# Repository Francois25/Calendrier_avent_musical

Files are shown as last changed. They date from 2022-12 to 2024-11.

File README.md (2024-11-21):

# Calendrier de l'Avent musical :

Ce calendrier de l'Avent utlise un ESp32-TTGO-T-Display permettant d'alimenter un circuit sur lequel 2 circuits intégrés CD4511 sont couplés à un circuit intégré CD40106 pour allumé aléatoirement 24 leds et jouer des musiques de Noël.
Les leds sont placé sur un plateau en bois décoré de 23 maisonnettes et une église simulants les 24 jours avant le jour de Noël).
Le déclenchement des musiques et de l'éclairage par clignottement aléatoire est défini selon la date et l'heure, tous les jours à 18h30 l'éclairage s'allume et il s'éteind automatiquement à 22h, il est toutefois possible d'allumer ou d'éteindre manuellement ces fonctions à l'aide de bouton sensitif.
Lors de l'appui sur un jour souhaité sur la partie NOEL de la décoration, la led relié s'illumine avec plus d'intensité pour repérer facilement la maisonnette correspondante.

# Firmware Micropython :
Le firmware utilisé est Micropython, disponible dans le répertoire [Firmware](https://github.com/Francois25/Calendrier_avent_musical/tree/main/firmware)

# Fonctionnement :
Dans un premier temps il faut créer un fichier config.py qui contiendra les valeur pour la connection réseau, ssid = "your_ssid" et password = "your_password".
Lors de la mise sous tension du module celui-ci va se connecter à votre réseau wifi interne et récupérer les données NTP (Network Time Protocol), la date et l'heure pour faire simple.

Au début du fichier "main" il y a les parametre des heures qu'on souhaite pour l'automatisation de l'alumage et de la lecture de la musique :
allumage des led clignottantes à partir de l'heure =>   START_HOUR = 18
allumage des led clignottantes à partir de l'heure =>   STOP_HOUR = 21
lancement de la musique 1x par jour à l'heure =>        MUSIC_HOUR_MIN = 17
fin de la musique automatique toute les heure à =>      MUSIC_HOUR_MAX = 20

L'ESP32 est alimenté via l'USB-C par une batterie 5V. Les pin 2 et 15 de l'ESP sont utilisés en tant que touch-pin, lorsque la pin 15 est touchée par l'utilisateur le circuit intégré CD4511 est alors alimenté et gènère un alumage aléatoire des 24 leds des maisonnettes via les circuits intégrés CD40106 (12 led par circuit). Lorsque la pin 2 est touchée l'ESP choisi au hasard une musique de la bibliothère des musiques de Noël et la diffuse sur le buzzer. Pendant le temps que la musique est jouée il n'est pas possible d'éteindre les lumières qui clignottent aléatoirement.
Lors de l'appui sur un bouton date du bloc Noël, celui-ci étant relié à la borne 5V de l'ESP32 la led 12V associée s'illumine avec une intensité plus importante, ce qui permet de repèrer facilement la maisonnette associée.

# Suppléments :
Tous les fichiers destinés à la fabrication des maisonnettes et de l'églises sont disponibles dans le répertoire [CNC_program](https://github.com/Francois25/Calendrier_avent_musical/tree/main/Doc/CNC_program)
Les fichiers destinés à la réalisation du PCB, les composants utilisé ainsi que le cablage sont disponibles dans le répertoire [Electronic](https://github.com/Francois25/Calendrier_avent_musical/tree/main/Doc/Electronic)
Les fichiers destinés à la réalisation du boitier recevant l'électronique et du cloché de l'église sont disponibles dans le répertoire [3D_Stl](https://github.com/Francois25/Calendrier_avent_musical/tree/main/Doc/3D_stl)

# Remerciement :
Un merci tout particulier à Monsieur Jacky BEURET. J'ai utilisé et étoffé son circuit de base trouvé par hasard sur internet. [Jeu de lumière aléatoire](http://www.electronique-3d.fr/Jeu_de_lumiere_aleatoire.html). N'hésitez pas à jetter un oeil à son site il y a plein de chose à se bricoler.
Adresse du site de M. BEURET : [Site internet](http://www.electronique-3d.fr/index.html)
Page Facebook de M. BEURET : [Facebook](https://www.facebook.com/profile.php?id=100054204263511)

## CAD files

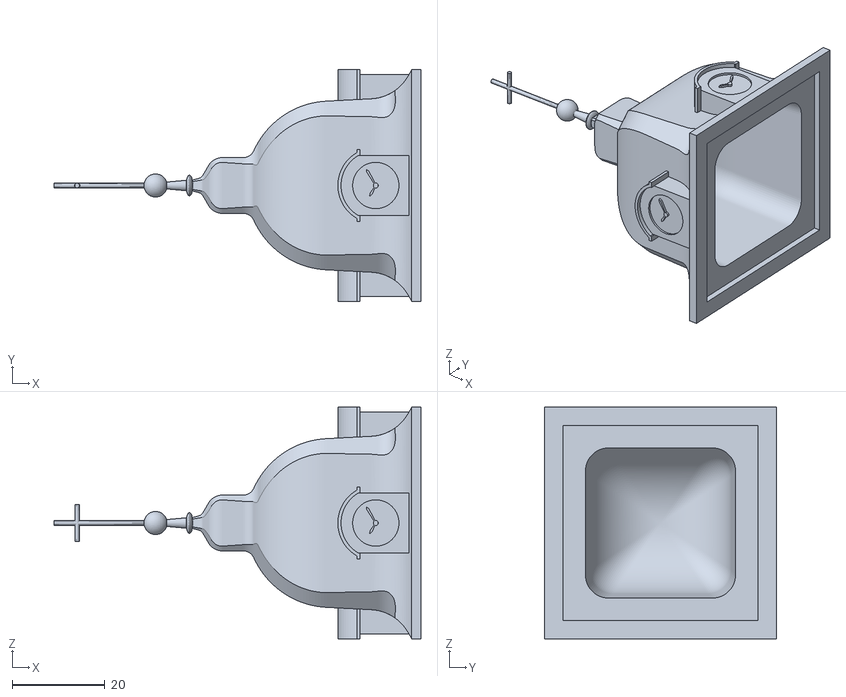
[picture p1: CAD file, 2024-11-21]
Docs/3D_stl/church_top.stl
79.2 x 50.0 x 50.0

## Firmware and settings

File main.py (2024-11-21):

from machine import Pin, PWM, Timer, TouchPad
from time import sleep_ms, sleep
from musiques import liste_music
import time, utime, ntptime
import musiques
import random
import wificonnect
import config

# allumage des leds à la demande --> ok
# 18h00 allumage des les clignotantes --> ok
# 22h extinction des leds clignotantes --> ok
# jouer des champs de Noel à la demande --> ok
# jouer des champts de Noel à heure précise --> ok
# allumage de la led du jour pour trouver le cadeau par appui sur bouton --> ok

ipaddress = wificonnect.connectSTA(ssid=config.ssid, password=config.password)
time.sleep(3)

TOUCH_CONFIG = 600
TOUCHE_ACTIVATION = 300
START_HOUR = 18
STOP_HOUR = 21
MUSIC_HOUR_MIN = 17
MUSIC_HOUR_MAX = 20

touch_music = TouchPad(Pin(2))
touch_music.config(TOUCH_CONFIG)

touch_OnOff = TouchPad(Pin(15))
touch_OnOff.config(TOUCH_CONFIG)

led_aleatoire = Pin(21, Pin.OUT, 0)
buzzer = PWM(Pin(27, Pin.OUT))
buzzer.init(duty=0)
timer = Timer(0)

# Recuperation de la date et heure via le réseau wifi
try:
    ntptime.settime()
    print("Connecté au serveur NTP")
    print("Heure locale: ", utime.localtime())
    time.sleep(1)
except:
    print("Connection au serveur NTP échouée !!")
    buzzer.duty(50)


def musique():
    choix = musiques.random.choice(tuple(liste_music.values()))
    musiques.play(choix[0], choix[1], choix[2])

def allumage_demande():
    # allumer ou éteindre l'éclairage aléatoire manuellement
    if touch_OnOff.read() <= TOUCHE_ACTIVATION and led_aleatoire.value() == 1:
        led_aleatoire.value(0)
        print('eclairage eteint')
    elif touch_OnOff.read() <= TOUCHE_ACTIVATION and led_aleatoire.value() == 0:
        led_aleatoire.value(1)
        print('eclairage allumé')
    else:
        return

def handleInterrupt(timer):
    date_jour = utime.localtime()
    decalage_UTC = 1
    heure = date_jour[3] + decalage_UTC
    minute = date_jour[4]
    jour = date_jour[2]
    mois = date_jour[1]
    annee = date_jour[0]
    print(f"jour : {jour}/{mois}/{annee} - Heure : {heure}:{minute}")
    print(f"Mesure touch :\nmusic: {touch_music.read()}\nOn - Off: {touch_OnOff.read()}")
    print("etat eclairage : ", led_aleatoire.value())
    print(jour, "/", heure, ":",minute)

    # jouer une musique par appui bouton sensitif 
    if touch_music.read() <= TOUCHE_ACTIVATION:
        musique()

    # Avant Noël
    if jour < 25:
        print("configuration : Avant Noël")
        # jouer une musique toutes les heures dans un creneau défini MUSIC_HOUR_MIN et MUSIC_HOUR_MAX
        heure_musique = MUSIC_HOUR_MIN
        minute_musique = 30
        if (heure == heure_musique and minute == minute_musique) and (MUSIC_HOUR_MIN <= heure < MUSIC_HOUR_MAX):
            musique()
            heure_musique += 1
            print("heure prochaine musique auto : ", heure_musique)
            time.sleep(50)
        if heure_musique > MUSIC_HOUR_MAX:
            heure_musique = MUSIC_HOUR_MIN
        
        # alumage aléatoire auto
        if (START_HOUR <= heure < STOP_HOUR) and led_aleatoire.value() == 0:
            led_aleatoire.value(1)
            return
        elif heure >= STOP_HOUR and led_aleatoire.value() == 1:
            led_aleatoire.value(0)
        else:
            allumage_demande()

    # Jour de Noël
    elif date_jour == 25:
        print("configuration : jour de Noël") 
        if 6 < heure < 17 and led_aleatoire.value() == 0:
            led_aleatoire.value(1)
            return
        else:
            allumage_demande()

    # Après Noël, allumage à la demande uniquement
    else:
        print("configuration : Après Noël")
        allumage_demande()


timer.init(period=1000, mode=Timer.PERIODIC, callback=handleInterrupt)

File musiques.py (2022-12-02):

import machine
from machine import Pin, PWM
import time
import random

pin = Pin(27, Pin.OUT)

# These are the notes with equivalent frequency
B0  = 31
C1  = 33
CS1 = 35
D1  = 37
DS1 = 39
E1  = 41
F1  = 44
FS1 = 46
G1  = 49
GS1 = 52
A1  = 55
AS1 = 58
B1  = 62
C2  = 65
CS2 = 69
D2  = 73
DS2 = 78
E2  = 82
F2  = 87
FS2 = 93
G2  = 98
GS2 = 104
A2  = 110
AS2 = 117
B2  = 123
C3  = 131
CS3 = 139
D3  = 147
DS3 = 156
E3  = 165
F3  = 175
FS3 = 185
G3  = 196
GS3 = 208
A3  = 220
AS3 = 233
B3  = 247
C4  = 262
CS4 = 277
D4  = 294
DS4 = 311
E4  = 330
F4  = 349
FS4 = 370
G4  = 392
GS4 = 415
A4  = 440
AS4 = 466
B4  = 494
C5  = 523
CS5 = 554
D5  = 587
DS5 = 622
E5  = 659
F5  = 698
FS5 = 740
G5  = 784
GS5 = 831
A5  = 880
AS5 = 932
B5  = 988
C6  = 1047
CS6 = 1109
D6  = 1175
DS6 = 1245
E6  = 1319
F6  = 1397
FS6 = 1480
G6  = 1568
GS6 = 1661
A6  = 1760
AS6 = 1865
B6  = 1976
C7  = 2093
CS7 = 2217
D7  = 2349
DS7 = 2489
E7  = 2637
F7  = 2794
FS7 = 2960
G7  = 3136
GS7 = 3322
A7  = 3520
AS7 = 3729
B7  = 3951
C8  = 4186
CS8 = 4435
D8  = 4699
DS8 = 4978
Z = 100000

def play(melodies, delays, duty):
    pwm = PWM(pin)
    pwm.duty_u16(32768)
    pwm.init(freq=5000, duty_ns=5000)

    for note in melodies:
        pwm.freq(note)
        pwm.duty(duty)
        time.sleep(delays)
    pwm.duty(0)
    pwm.deinit()

# This is the list of notes for mario theme
liste_music = {
    "mario" : [
        [E7, E7,  Z, E7,  Z, C7, E7,  Z,
        G7,  Z,  Z,  Z, G6,  Z,  Z,  Z,
        C7,  Z,  Z, G6,  Z,  Z, E6,  Z,
        Z, A6,  Z, B6,  Z,AS6, A6,  Z,
        G6, E7,  Z, G7, A7,  Z, F7, G7,
        Z, E7,  Z, C7, D7, B6,  Z,  Z,
        C7,  Z,  Z, G6,  Z,  Z, E6,  Z,
        Z, A6,  Z, B6,  Z,AS6, A6,  Z,
        G6, E7,  Z, G7, A7,  Z, F7, G7,
        Z, E7,  Z, C7, D7, B6,  Z,  Z,
        ], 0.15, 250],

# This is the list of notes for jingle, Jingle bells
    "jingle" : [
        [E7, E7, E7, Z,
        E7, E7, E7, Z,
        E7, G7, C7, D7, E7, Z,
        F7, F7, F7, F7, F7, E7, E7, E7, E7, D7, D7, E7, D7, Z, G7, Z,
        E7, E7, E7, Z,
        E7, E7, E7, Z,
        E7, G7, C7, D7, E7, Z,
        F7, F7, F7, F7, F7, E7, E7, E7, G7, G7, F7, D7, C7, Z 
        ], 0.25 , 512],

# This is the list of notes for Twinkle, Twinkle Little Star
    "twinkle" : [
        [C6, C6, G6, G6, A6, A6, G6, Z,
        F6, F6, E6, E6, D6, D6, C6, Z,
        G6, G6, F6, F6, E6, E6, D6, Z,
        G6, G6, F6, F6, E6, E6, D6, Z,
        C6, C6, G6, G6, A6, A6, G6, Z,
        F6, F6, E6, E6, D6, D6, C6, Z,
    ],0.6, 50],

# This is the list of notes for Jolly, Jolly Old St. Nicholas
    "jolly" : [
        [E6, Z, E6, Z, E6, Z, E6, Z, D6, Z, D6, Z, D6, D6, D6, Z,
        C6, Z, C6, Z, C6, Z, C6, Z, E6, E6, E6, Z, Z, Z, Z, Z,
        A5, Z, A5, Z, A5, Z, A5, Z, C5, Z, G5, Z, C5, C5, C5, Z,
        D6, C6, D6, E6, D6, D6, Z, Z, Z,
        E6, Z, E6, Z, E6, Z, E6, Z, D6, Z, D6, Z, D6, D6, D6, Z,
        C6, Z, C6, Z, C6, Z, C6, Z, E6, E6, E6, Z, Z, Z, Z, Z,
        A5, Z, A5, Z, A5, Z, A5, Z, C5, Z, G5, Z, C5, C5, C5, Z,
        D6, C6, D6, E6, C6, C6, C6, Z,
    ],0.12, 250],

# This is the list of notes for Wish, We wish you a merry Christmas
    "wish" : [
        [G5, Z, C6, Z, C6, D6, C6, B5, A5, Z, A5, Z, A5, Z,
        D6, Z, D6, E6, D6, C6, B5, Z, G5, Z, G5, Z,
        E6, Z, E6, F6, E6, D6, C6, Z, A5, Z, G5, Z,
        A5, A5, D6, D6, B5, B5, C6, C6, C6, Z,
        G5, Z, C6, Z, C6, D6, C6, B5, A5, Z, A5, Z, A5, Z,
        D6, Z, D6, E6, D6, C6, B5, Z, G5, Z, G5, Z,
        E6, Z, E6, F6, E6, D6, C6, Z, A5, Z, G5, Z, G5, Z,
        A5, A5, D6, D6, B5, B5, C6, C6, C6,
    ],0.2, 120],

# This is the list of notes for Vive, Vive le vent
    "vive" : [
        [E6, Z, E6, Z, E6, E6, E6, Z, E6, Z, E6, Z, E6, E6, E6, Z,
        E6, Z, G6, Z, C6, Z, D6, Z, E6, E6, E6, E6, Z, Z, Z, Z,
        F6, Z, F6, Z, F6, F6, F6, G6, E6, Z, E6, Z, E6, E6, E6,
        C6, D6, Z, D6, Z, D6, Z, E6, Z, D6, D6, Z, Z, G6, G6, G6, Z,
        E6, Z, E6, Z, E6, E6, E6, Z, E6, Z, E6, Z, E6, E6, E6, Z,
        E6, Z, G6, Z, C6, Z, D6, Z, E6, E6, E6, E6, Z, Z, Z, Z,
        F6, Z, F6, Z, F6, F6, F6, G6, E6, Z,  E6, Z, E6, E6, Z,
        E6, G6, Z, G6, Z, F6, Z, D6, Z, C6, C6, C6, Z,
    ],0.14, 250],

# This is the list of notes for Papa, Petit papa Noël
     "papa" : [
        [G5, G5, C6, Z, C6, Z, C6, Z, D6, Z, C6, C6, C6, C6, C6, Z,
        C6, D6, E6, Z, E6, Z, E6, Z, F6, Z, E6, E6, E6, E6, E6, Z,
        D6, D6, C6, C6, C6, Z, C6, C5, C6, B5, A5, G5, G5, G5, G5, Z,
        G5, C5, C6, C6, C6, C6, Z, C6, C5, B5, C5, D6, D6, D6, Z,
        G5, G5, C6, Z, C6, Z, C6, Z, D6, Z, C6, C6, C6, C6, C6, Z,
        C6, D6, E6, Z, E6, Z, E6, Z, F6, Z, E6, E6, E6, E6, E6, Z,
        D6, D6, C6, C6, C6, Z, C6, C5, C6, B5, A5, G5, G5, G5, G5, Z,
        G5, C5, C6, C6, C6, C6, Z, C6, C5, D6, D5, C6, C6, C6, C6, Z,
    ],0.20, 250],

# This is the list of notes for Sapin, Mon beau sapin
    "sapin" : [
        [G5, G5, C6, C5, C6, C6, C6, Z,
        D6, D6, E6, E5, E6, E6, E6, Z,
        E6, D6, E6, F5, F5, B5, B5, D6, D6, C6, C6, C6, Z,
        G5, G6, E6, A6, A6, A6, Z, G5, G6, F5, F5, F5, Z,
        G5, G6, D6, G6, G6, G6, Z, F5, F6, E6, E6, E6, Z,
        G5, G5, C6, C5, C6, C6, C6, Z,
        D6, D6, E6, E5, E6, E6, E6, Z,
        E6, D6, E6, F5, F5, B5, B5, D6, D6, D6, D6, C6, C6, C6, C6, C6, Z,
    ],0.30, 250],
    
# This is the list of notes for Douce, Douce nuit
    "douce" : [
        [G6, G6, G6, A6, G6, G6, E6, E6, E6, E6, E6, Z,
         G6, G6, G6, A6, G6, G6, E6, E6, E6, E6, E6, Z,
         D6, D6, D6, Z, D6, D6, B5, B5, B5, B5, Z,
         C6, C6, C6, Z, C6, C6, G5, G5, G5, G5, Z,
         A5, A5, A5, Z, A5, A5, C6, C6, C6, B5, A5, A5, G5, G5, G5, A5, G5, G5, E5, E5, E5, E5, Z, Z,
         A5, A5, A5, Z, A5, A5, C6, C6, C6, B5, A5, A5, G5, G5, G5, A5, G5, G5, E5, E5, E5, E5, Z, Z,
         D6, D6, D6, Z, D6, D6, F6, F6, F6, D6, B5, B5, C6, C6, C6, C6, C6, E6, E6, E6, E6, Z, Z,
         C6, C6, C6, G5, E5, E5, G5, G5, G5, F5, D5, D5, C5, C5, C5, C5, C5, C5, C5, C5, Z,
    ],0.28, 250],

}

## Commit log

2022-12-02 ajout de nouvelle musiques
2022-12-16 fichier stl toit eglise
    [church_top.stl]
2022-12-16 fichier stl arbre
